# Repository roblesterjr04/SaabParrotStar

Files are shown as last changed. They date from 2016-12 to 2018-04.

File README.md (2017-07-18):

# SaabParrotStar
Arduino project designed to interface between Saab's onstar buttons and a parrot CK3000 evo handsfree unit.

## Operation
### Standby
|Button |Action |Function |
|:---:|:---:|:---:|
|*OnStar* |Press Once|Activate Siri/Answer Call|
|-- |Hold |Redial |
|Dot |Press Once|Enter Menu |
|-- |Hold |Enable/Disable Aux 1 |
|Red Cross  |Press Once|-- |
|-- |Hold |Enable/Disable Aux 2 |
|-- |Long Hold |Reset Parrot |

### In Call
|Button |Action |Function |
|:---:|:---:|:---:|
|*OnStar* |Press Once|Call Waiting/Private Mode|
|-- |Hold |Redial |
|Dot |Press Once|Volume Up |
|-- |Hold |Volume Down |
|Red Cross  |Press Once|Hang Up |
|-- |Hold |Hang Up |

### Menu Operation
|Button |Action |Function |
|:---:|:---:|:---:|
|*OnStar* |Press Once|Select |
|-- |Hold |-- |
|Dot |Press Once|Down |
|-- |Hold |-- |
|Red Cross  |Press Once|Up |
|-- |Hold |Exit |

## Board Version History
### Version *1.0 (A328.brd)*
This board uses the ATMega328P chip and an external 16MHz crystal. Chip should be bootloaded and programmed before installed on the board. The traces for the 12V switching relays are rated for 1.42A, though the G5V1 relays are only rated at 1A. All traces can handle up to 440mA. The lettering on the connectors are wire color for the 4 pin cable, and by purpose on the 5 pin. The pinout for the 5 pin is so: *P = Power/5v (out), E = Earth/Gnd, A = Analog signal, G = Green Led, R = Red Led*. The pinout for the 4 pin molex is so: *Y = Power/12v (in), B = Earth/Gnd, R = TX, Bl = RX*. The ATMega328P has only one serial port, so the code must be modified to use Serial0, not Serial1 as it is now for development/prototype. The chip needs to be mounted in a socket, as 2 of the resistors are placed under the ship in the recesses of the socket.



## Future Ideas...
Will like to build CK3100 compatability to allow for text display to be piped in to CAN bus and display on Saab's SID display. Would also like to conceive a method to integrate steering wheel controls. Should not be too challenging since they are also an analog circuit.

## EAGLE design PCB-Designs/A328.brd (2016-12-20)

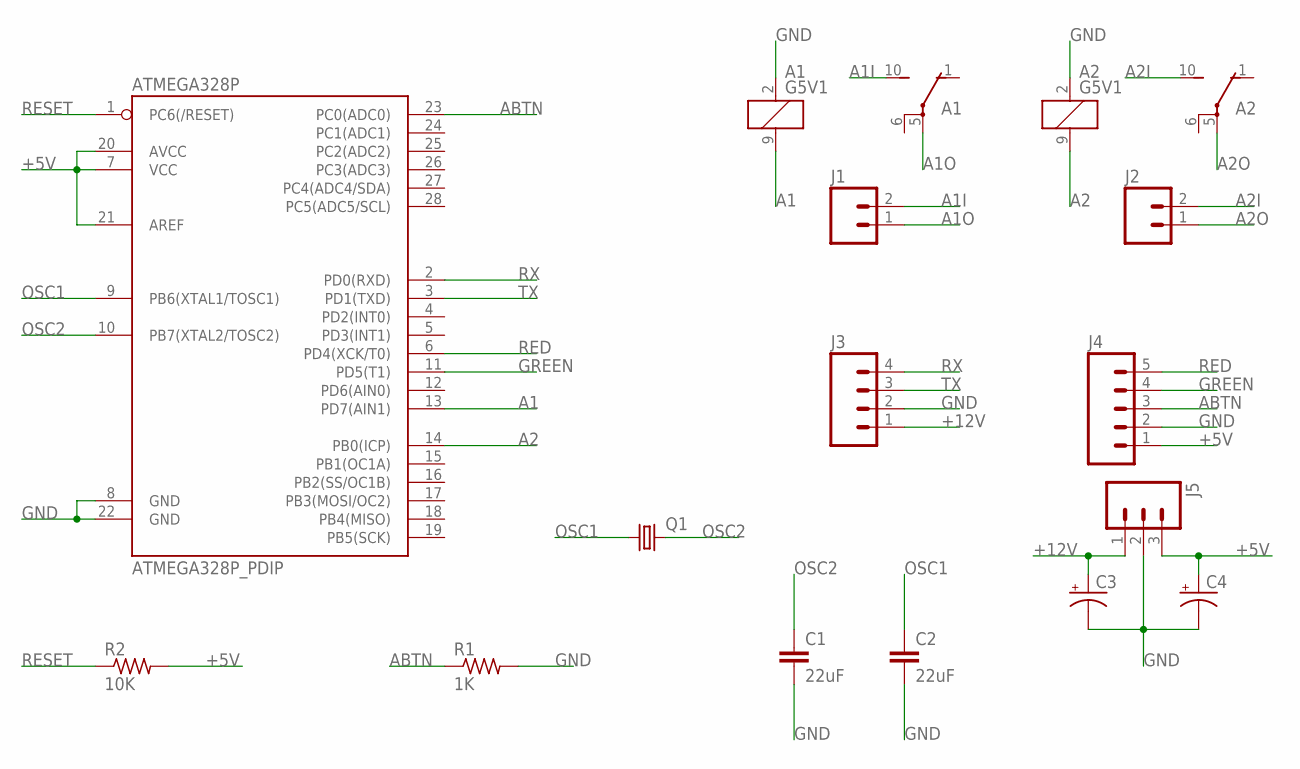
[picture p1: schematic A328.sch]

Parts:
A1, A2: G5V1
ATMEGA328P: ATMEGA328P_PDIP; DIL28-3
C1, C2: 22uF; CAP-PTH-SMALL-KIT
C3, C4: 10UF-25V-20%(PTH); CPOL-RADIAL-10UF-25V
J1, J2: M02PTH3; 1X02_LONGPADS
J3: M04NO_SILK_ALL_ROUND; 1X04_NO_SILK_ALL_ROUND
J4: M05NO_SILK; 1X05_NO_SILK
J5: M03LONGPADS; 1X03_LONGPADS
Q1: CRYSTALHC49S; HC49/S
R1: 1K; 0204/7
R2: 10K; 0204/7

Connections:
+5V: ATMEGA328P.7 (VCC), ATMEGA328P.20 (AVCC), ATMEGA328P.21 (AREF), C4.1 (+), J4.1, J5.3, R2.2
+12V: C3.1 (+), J3.1, J5.1
A1: A1.9 (2), ATMEGA328P.13 (PD7(AIN1))
A1I: A1.10 (S), J1.2
A1O: A1.5, J1.1
A2: A2.9 (2), ATMEGA328P.14 (PB0(ICP))
A2I: A2.10 (S), J2.2
A2O: A2.5, J2.1
ABTN: ATMEGA328P.23 (PC0(ADC0)), J4.3, R1.1
GND: A1.2 (1), A2.2 (1), ATMEGA328P.8 (GND), ATMEGA328P.22 (GND), C1.2, C2.2, C3.2 (-), C4.2 (-), J3.2, J4.2, J5.2, R1.2
GREEN: ATMEGA328P.11 (PD5(T1)), J4.4
OSC1: ATMEGA328P.9 (PB6(XTAL1/TOSC1)), C2.1, Q1.1
OSC2: ATMEGA328P.10 (PB7(XTAL2/TOSC2)), C1.1, Q1.2
RED: ATMEGA328P.6 (PD4(XCK/T0)), J4.5
RESET: ATMEGA328P.1 (PC6(/RESET)), R2.1
RX: ATMEGA328P.2 (PD0(RXD)), J3.4
TX: ATMEGA328P.3 (PD1(TXD)), J3.3

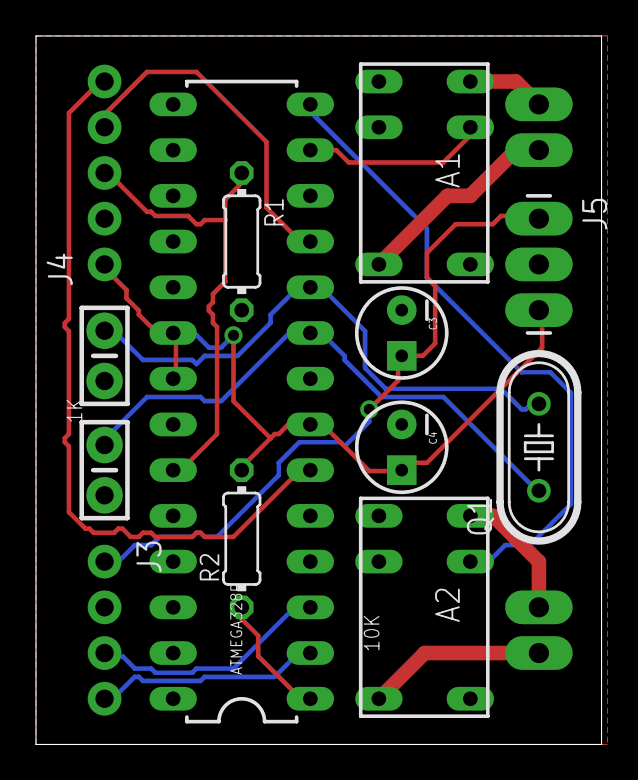
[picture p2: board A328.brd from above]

Board: 2 copper layers, 31.4 x 39.4 mm, 15 parts (0 on the bottom side), 17 nets.

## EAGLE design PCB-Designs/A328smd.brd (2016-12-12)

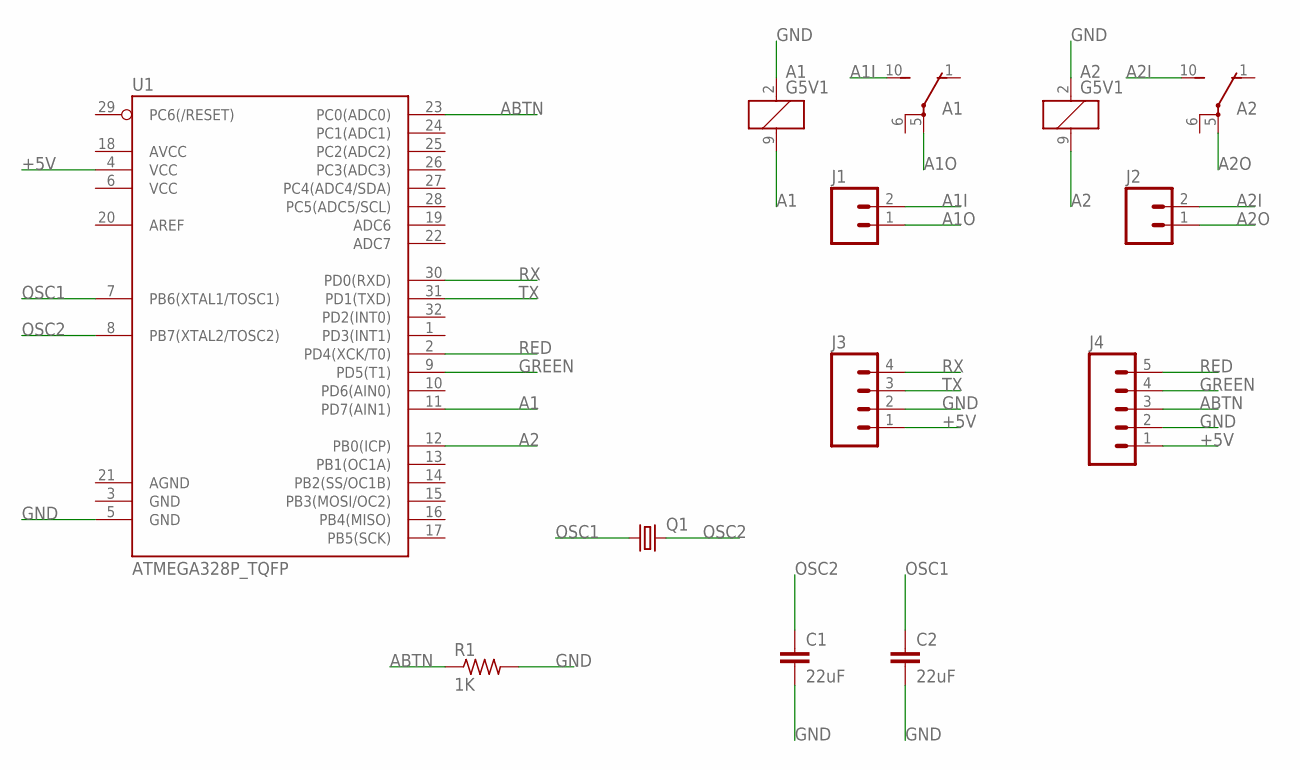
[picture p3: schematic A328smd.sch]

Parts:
A1, A2: G5V1
C1, C2: 22uF; 1210
J1, J2: M02PTH3; 1X02_LONGPADS
J3: M04NO_SILK_ALL_ROUND; 1X04_NO_SILK_ALL_ROUND
J4: M05NO_SILK; 1X05_NO_SILK
Q1: CRYSTALSM49; SM49
R1: 1K; M1206
U1: ATMEGA328P_TQFP; TQFP32-08

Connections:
+5V: J3.1, J4.1, U1.4 (VCC)
A1: A1.9 (2), U1.11 (PD7(AIN1))
A1I: A1.10 (S), J1.2
A1O: A1.5, J1.1
A2: A2.9 (2), U1.12 (PB0(ICP))
A2I: A2.10 (S), J2.2
A2O: A2.5, J2.1
ABTN: J4.3, R1.1, U1.23 (PC0(ADC0))
GND: A1.2 (1), A2.2 (1), C1.2, C2.2, J3.2, J4.2, R1.2, U1.5 (GND)
GREEN: J4.4, U1.9 (PD5(T1))
OSC1: C2.1, Q1.1, U1.7 (PB6(XTAL1/TOSC1))
OSC2: C1.1, Q1.2, U1.8 (PB7(XTAL2/TOSC2))
RED: J4.5, U1.2 (PD4(XCK/T0))
RX: J3.4, U1.30 (PD0(RXD))
TX: J3.3, U1.31 (PD1(TXD))

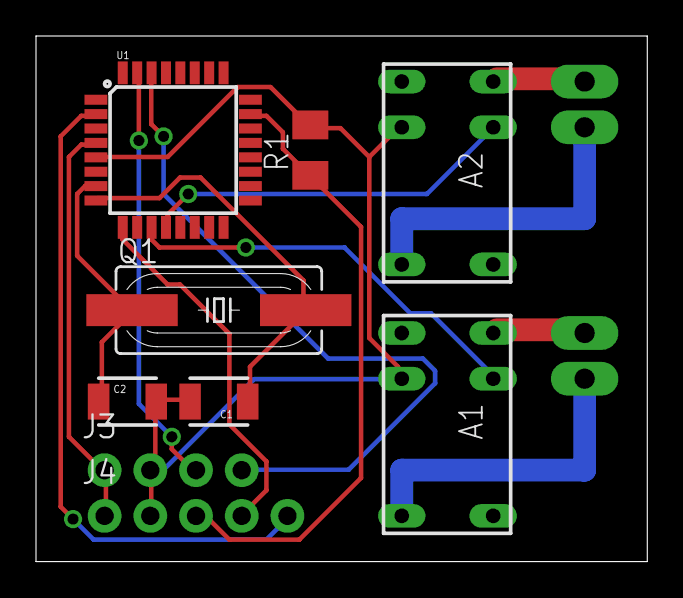
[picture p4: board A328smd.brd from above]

Board: 2 copper layers, 34.0 x 29.2 mm, 11 parts (0 on the bottom side), 15 nets.

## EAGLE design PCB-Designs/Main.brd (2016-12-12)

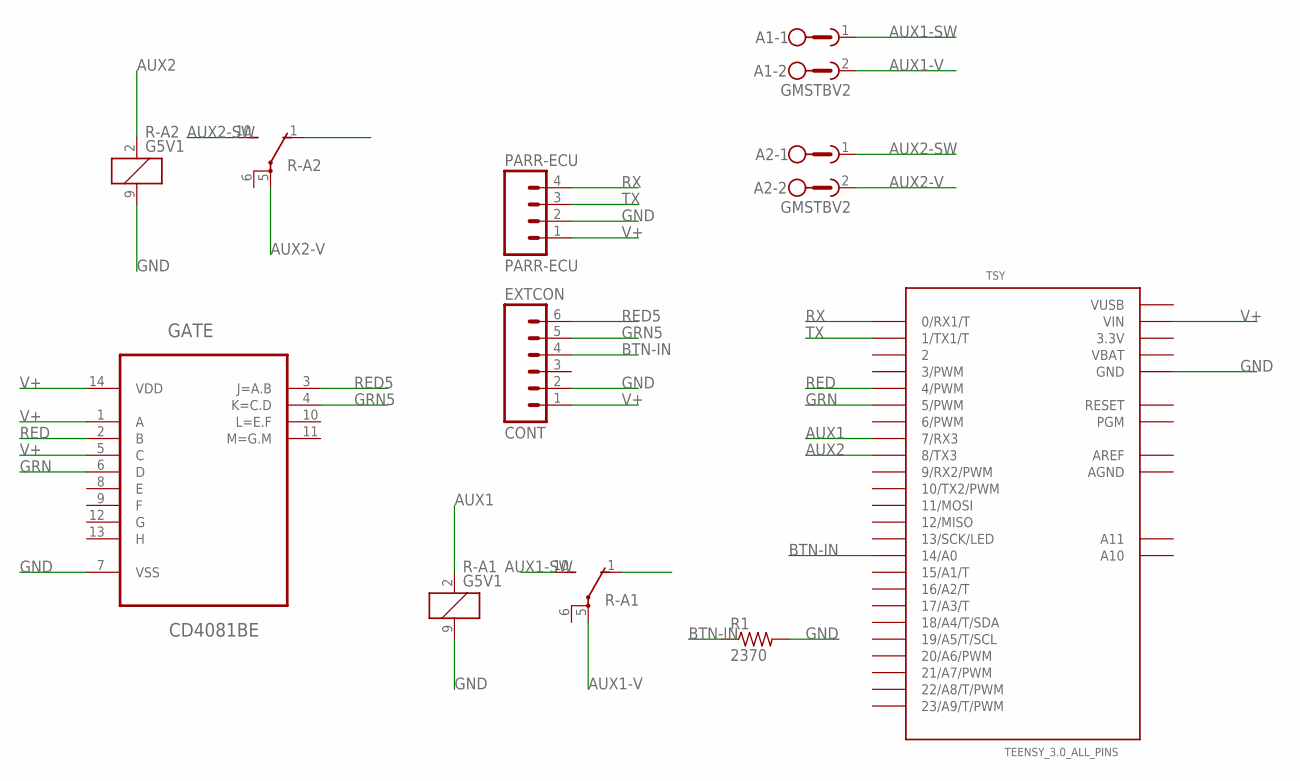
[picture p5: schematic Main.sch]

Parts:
A1, A2: GMSTBV2
EXTCON: CONT; 1X06_NO_SILK
GATE: CD4081BE; DIP254P762X508-14
PARR-ECU: PARR-ECU; 1X04_NO_SILK_ALL_ROUND
R1: 2370; 0207/10
R-A1, R-A2: G5V1
TSY: TEENSY_3.0_ALL_PINS; TEENSY_3.0-3.2&LC_ALL_PINS

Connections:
3.3V: TSY.3.3V, TSY.3.3V1 (3.3V)
AGND: TSY.AGND
AREF: TSY.AREF
AUX1: R-A1.2 (1), TSY.7 (7/RX3)
AUX1-SW: A1.1, R-A1.10 (S)
AUX1-V: A1.2, R-A1.5
AUX2: R-A2.2 (1), TSY.8 (8/TX3)
AUX2-SW: A2.1, R-A2.10 (S)
AUX2-V: A2.2, R-A2.5
BTN-IN: EXTCON.4, R1.1, TSY.14/A0
GND: EXTCON.2, GATE.7 (VSS), PARR-ECU.2, R1.2, R-A1.9 (2), R-A2.9 (2), TSY.GND, TSY.GND1 (GND)
GRN: GATE.6 (D), TSY.5 (5/PWM)
GRN5: EXTCON.5, GATE.4 (K=C.D)
RED: GATE.2 (B), TSY.4 (4/PWM)
RED5: EXTCON.6, GATE.3 (J=A.B)
RX: PARR-ECU.4, TSY.0 (0/RX1/T)
TX: PARR-ECU.3, TSY.1 (1/TX1/T)
V+: EXTCON.1, GATE.1 (A), GATE.5 (C), GATE.14 (VDD), PARR-ECU.1, TSY.VIN
VBAT: TSY.VBAT
VUSB: TSY.VUSB

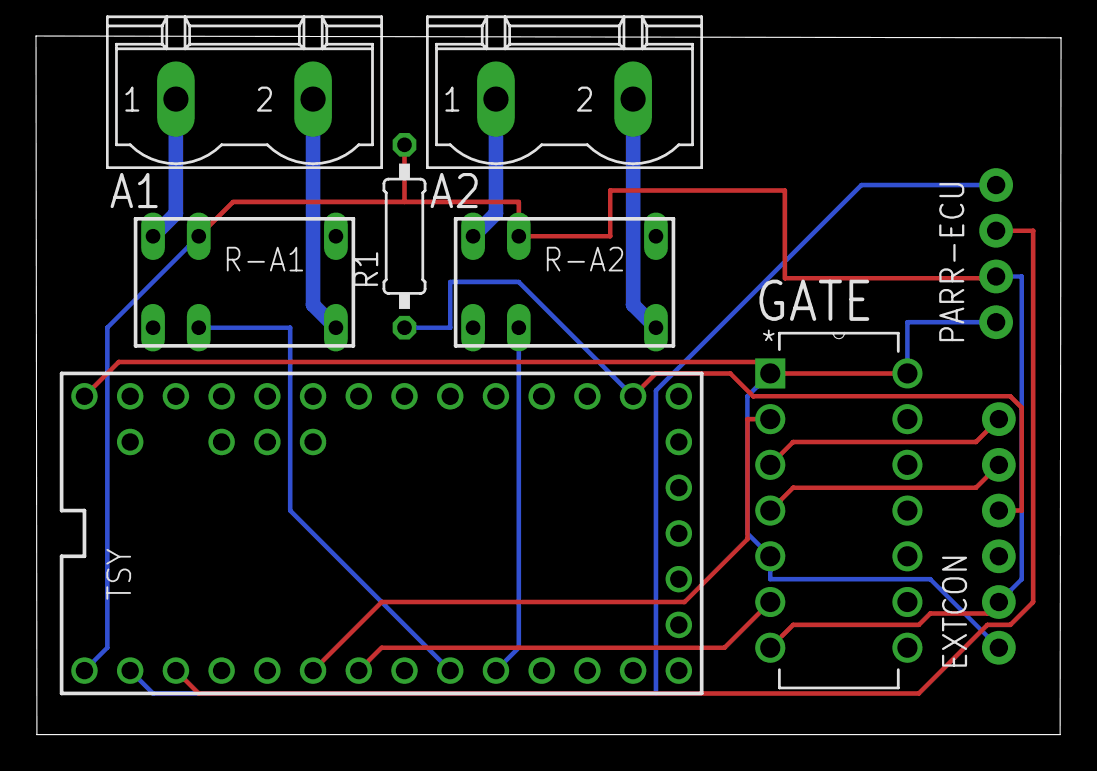
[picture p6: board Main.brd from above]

Board: 2 copper layers, 56.9 x 38.8 mm, 9 parts (0 on the bottom side), 16 nets.

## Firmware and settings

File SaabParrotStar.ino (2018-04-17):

//#########################################################
//###                                                   ###
//###            Saab ParrotStar BT Control             ###
//###                  Version 1.2.4                    ###
//###                    Rob Lester                     ###
//###               Hardware: Atmega328p                ###
//###                                                   ###
//#########################################################

#include <EEPROM.h>

// Operational Values
long millis_held;
unsigned long firstTime = 0;
int previous = 0;
int current = 0;
int executed = 0;

// The analog ranges need to be determined. When a button is pressed, 
// the value is printed to the console.

// Below ranges based on a 1K resistor pulling down the button value line.

// Button 1 analog range
int btn1low = 200;
int btn1high = 300;

// Button 2 analog range
int btn2low = 50;
int btn2high = 200;

// Button 3 analog range
int btn3low = 350;
int btn3high = 500;

// Button Press Debounce/Longpress settings
int longpress = 1000; //How long should a long press be
int presstimeout = 200; //Set the firsttime value after this long of a press.
int low = 5; //Set the low threshold of the analog input. Anything below this will count as null/0/zilch. 

// Comms - don't change these
int conRes = 128;
int stopLoop = 0;
int lastComm = 0;

// PINS
int greenPin = 5;
int redPin = 4;
int buttonPin = 0; // Analog Pin for Control Buttons.
int auxPin1 = 7; // Control an aux relay if included in circuit.
int auxPin2 = 8; // Control an aux relay if included in circuit. 2 seems useful.
int ledPin = 13; // On Board LED

int auxPinMem1 = 0; // Aux 1 setting byte on EEPROM
int auxPinMem2 = 1; // Aux 2 setting byte on EEPROM

// Context Flags
int menu = 0;
int resetConfirm = 0;
int inCall = 0;
int ringing = 0;

// Debug data
int debug = false;

int at328 = true;

#define box Serial

void setup() { // Initial Boot Sequence
	
	pinMode(greenPin, OUTPUT);
	pinMode(redPin, OUTPUT);
	pinMode(ledPin, OUTPUT);
	pinMode(auxPin1, OUTPUT);
	pinMode(auxPin2, OUTPUT);
	box.begin(9600);
	digitalWrite(auxPin1, EEPROM.read(auxPinMem1));
	digitalWrite(auxPin2, EEPROM.read(auxPinMem2));
	digitalWrite(ledPin, 1);
}
void(* resetFunc) (void) = 0;

void loop() { // 
	readAnalogController(); //Listen for analog button commands.
	
	// Tell parrot brain Box that we are waiting.
	if (!stopLoop) {
		box.write(160);
		box.write(128);
		delay(250);
		int bl = digitalRead(greenPin);
		digitalWrite(greenPin, !bl);
    //digitalWrite(ledPin, !bl);
	}
}

void debugPrint(String message) {
	if (!debug) return;
	if (at328) {
		box.println(message);
	} else {
		Serial.println(message);
	}
}

void serialEvent() { // Receive commands from the brain box
	
	if (stopLoop == 0) {
		stopLoop = 1; // Stop the waiting loop, because the box has come online.
		digitalWrite(ledPin, LOW);
	}

	int v = box.read();
	
	// Process specific commands from box
	
	if (v == 34) { 
		// At rest
		digitalWrite(greenPin, LOW);
		digitalWrite(redPin, LOW);
		inCall = 0;
		menu = 0;
		ringing = 0;
	}
	if (v == 17) { 
		// Phone is engaged
		digitalWrite(greenPin, HIGH);
		digitalWrite(redPin, LOW);
		inCall = 1;
		menu = 0;
		ringing = 0;
	}
	if (v == 2 || v == 32) {
		// Menu State
		digitalWrite(greenPin, HIGH);
		digitalWrite(redPin, LOW);
		menu = 1;
		inCall = 0;
		ringing = 0;
	}
	if (v == 119) {
		int ledState = digitalRead(greenPin);
		digitalWrite(greenPin, !ledState);
		menu = 0;
		inCall = 0;
		ringing = 1;
	}
	
	// End specific commands
	
	// HANDSHAKE PROCESSING CODE BELOW
	
	// Part of the handshake
	if (lastComm == 160 && v == 1) {
		box.write(160);
		box.write(129);
		box.write(2);
	}
	
	// Part of the handshake -- Complete
	if (lastComm == 160 && v == 4) {
		box.write(160);
		box.write(132);
	}
	
	// Part of the handshake
	if (lastComm == 160 && conRes == 128) {
		box.write(160);
		box.write(131);
		conRes = 131;
	}

  readAnalogController();
	
	lastComm = v; // Set our last command
}

void readAnalogController() {
	delay(10);
	current = analogRead(buttonPin);
		
	if (previous > low && current <= low) {
		executed = 0;
	}
	
	if (previous > low && current <= low && millis_held < longpress) {
		int btn = decodeButton(previous);
		executeButton(btn, 0);
		debugPrint("Voltage: " + String(current));
		debugPrint("Button: " + String(btn));
	}
	
	if (current > low && previous <= low && (millis() - firstTime) > presstimeout) {
		firstTime = millis();
	}
	
	if (current > low) millis_held = (millis() - firstTime);
	else {
		millis_held = 0;
		firstTime = 0;
	}
	
	if (millis_held > longpress && executed == 0) {
	
		int btn = decodeButton(current);
		executeButton(btn, 1);
		executed = 1;
		debugPrint("Voltage: " + String(current));
		debugPrint("Button: " + String(btn));
				
	}
	
	if (millis_held > longpress * 10) {
		
		int btn = decodeButton(current);
		executeButton(btn, 2);
		
		debugPrint("Voltage: " + String(current));
		debugPrint("Button: " + String(btn));
		
	}
	
	previous = current;
}

int decodeButton(int value) {
	
	if (value > btn1low && value < btn1high) return 1;
	else if (value > btn2low && value < btn2high) return 2;
	else if (value > btn3low && value < btn3high) return 3;
	
	return 0;
  
}

void executeButton(int button, int press) {
	if (press == 1) {
		longPressButton(button);
	} else if (press == 2) {
		longHoldButton(button);
	} else {
		shortPressButton(button);
	}
}

void shortPressButton(int button) {
	switch (button) {
		case 1:
			if (menu) menuSelect();
			//else if (ringing) redial();
			else callButton();
			break;
		case 2:
			if (menu) down();
			else if (inCall) up();
			else menuSelect();
			break;
		case 3:
			if (menu) up();
			else endButton();
			break;
		default:
			break;
	}
}

void longHoldButton(int button) {
	switch (button) {
		case 1:
			break;
		case 2:
			break;
		case 3:
			reset();
			break;
		default:
			break;
	}
}

void longPressButton(int button) {
	switch (button) {
		case 1:
			redial();
			break;
		case 2:
			if (!menu && !inCall) auxEnable1();
			if (inCall) down();
			break;
		case 3:
			if (menu || inCall) endButton();
			else auxEnable2();
			break;
		default:
			break;
	}
}

void auxEnable1() {
	digitalWrite(auxPin1, !digitalRead(auxPin1));
	EEPROM.write(auxPinMem1, digitalRead(auxPin1));
	blinkLed(greenPin, 3);
}

void auxEnable2() {
	digitalWrite(auxPin2, !digitalRead(auxPin2));
	EEPROM.write(auxPinMem2, digitalRead(auxPin2));
	blinkLed(greenPin, 3);
}

// Blink an LED. Do not use inside the main loop, or the serial interrupts.
void blinkLed(int led, int times) {
	int counter = 0;
	while (counter < times) {
		digitalWrite(led, HIGH);
		delay(100);
		digitalWrite(led, LOW);
		delay(100);
		counter++;
	}
}

// Box specific functions
void command(int command) {
	box.write(160);
	box.write(130);
	box.write(command);
}

void releaseButton() {
	delay(150);
	command(0);
}

void callButton() {
	blinkLed(greenPin, 2);
	command(2);
	releaseButton();
}

void redial() {
	command(2);
}

void endButton() {
	command(1);
	releaseButton();
}

void menuSelect() {
	command(4);
	releaseButton();
}

void up() {
	command(8);
}

void down() {
	command(248);
}

void reset() {
	debugPrint("Resetting Device. Goodbye.");
	digitalWrite(greenPin, HIGH);
	resetConfirm = 0;
	command(3);
	delay(2000);
	digitalWrite(greenPin, LOW);
	EEPROM.update(auxPinMem1, LOW);
	EEPROM.update(auxPinMem2, LOW);
	resetFunc();
}

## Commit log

2016-12-07 Analog button signal final
    Read values against a 1k resistor and input to the code. Also removed
    the multi-press functions since multi-press doesn’t work on this
    circuit.
    [SaabParrotStar.ino]
2016-12-07 Code changes and fixes
    [SaabParrotStar.ino]
2016-12-07 Added software reset code
    Added test code to do a hard reset to the parrot module and clear its settings. Needed software reset for the controller so that a handshake could be re-established.
    [SaabParrotStar.ino]
2016-12-07 Removing serial references
    Will eventually remove all Serial.println because final design with atmega328 chip will only have a single Serial port, needed for comms with parrot.
2016-12-08 Code cleanup and values adjusted. Code is good for prototype board.
2016-12-12 Add PCB designs.
    [A328.brd, A328.sch, Main.brd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]
2016-12-12 Added information for beta1 board.
2016-12-12 Updating board files
    [A328.sch, A328smd.brd, A328smd.sch]
2016-12-13 Adjusted analog ranges for Teensy3.2
    there must be some noise on the circuit or the resistor i used before
    wasn’t quite 1K.
    [SaabParrotStar.ino]
2016-12-16 Working on final board compatible code.
2016-12-20 PCB Updates to the A328 board.
2016-12-20 Smaller board, redundant power according to arduino schematic.
    [A328.brd, A328.sch]
2016-12-20 Building in multi-chip compatability
    The Teensy does not have a “Serial 0”, it only has Serial 1,2,3 and “0”
    is a software emulation. The Atmega328p has only Serial0 as hardware.
    Building automatic detection of this in the code on compilation so that
    It doesn’t need to be changed per chip.
    [SaabParrotStar.ino]
2016-12-22 Code updates and button diagnostic functions.
2016-12-23 Disconnected the red pin
    Only using a 4 conductor cable to the buttons so there will be no red
    light. The board will support it, but I’ve removed the alternating
    red/green light code so the menu won’t be confusing.
    [SaabParrotStar.ino]
2017-01-06 Updated code to work with Atmega328 only
    Values needed to be tweaked and devices specific code needed to be
    removed. it wasn’t allowing the program to run and therefor didn’t work
    with the Parrot.
    [SaabParrotStar.ino]
2017-05-18 Bug fixes that may fix the problem with answering calls.
    [SaabParrotStar.ino]
2017-05-18 Changed button function slightly
    Remove volume down while in call. Make single press of dot to volume up, make single press of red x to hangup during call.
2017-06-14 Code prettifying
    Organizing code for understandability. Fixing bugs found in logic review.
    [SaabParrotStar.ino]
2017-07-11 Added board link
2017-08-03 Add ring status, light when big button pressed.
2018-04-17 Call the analog button reader during the serial response.

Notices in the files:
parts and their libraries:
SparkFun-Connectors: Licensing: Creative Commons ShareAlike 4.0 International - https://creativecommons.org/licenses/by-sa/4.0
